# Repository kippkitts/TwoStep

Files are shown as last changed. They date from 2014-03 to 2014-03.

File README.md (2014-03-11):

TwoStep
=======

<a href=http://kippkitts.com/collections/frontpage/products/twostep-stepper-controller-shield>

The TwoStep Controller is a stepper motor controller shield for the Arduino.  It uses two L6470 stepper drivers to drive two motors at 40V, 5A each.  Provided here are the Eagle files for the board.  You can find the TwoStep Controller at the [kippkitts store](http://kippkitts.com/collections/frontpage/products/twostep-stepper-controller-shield).

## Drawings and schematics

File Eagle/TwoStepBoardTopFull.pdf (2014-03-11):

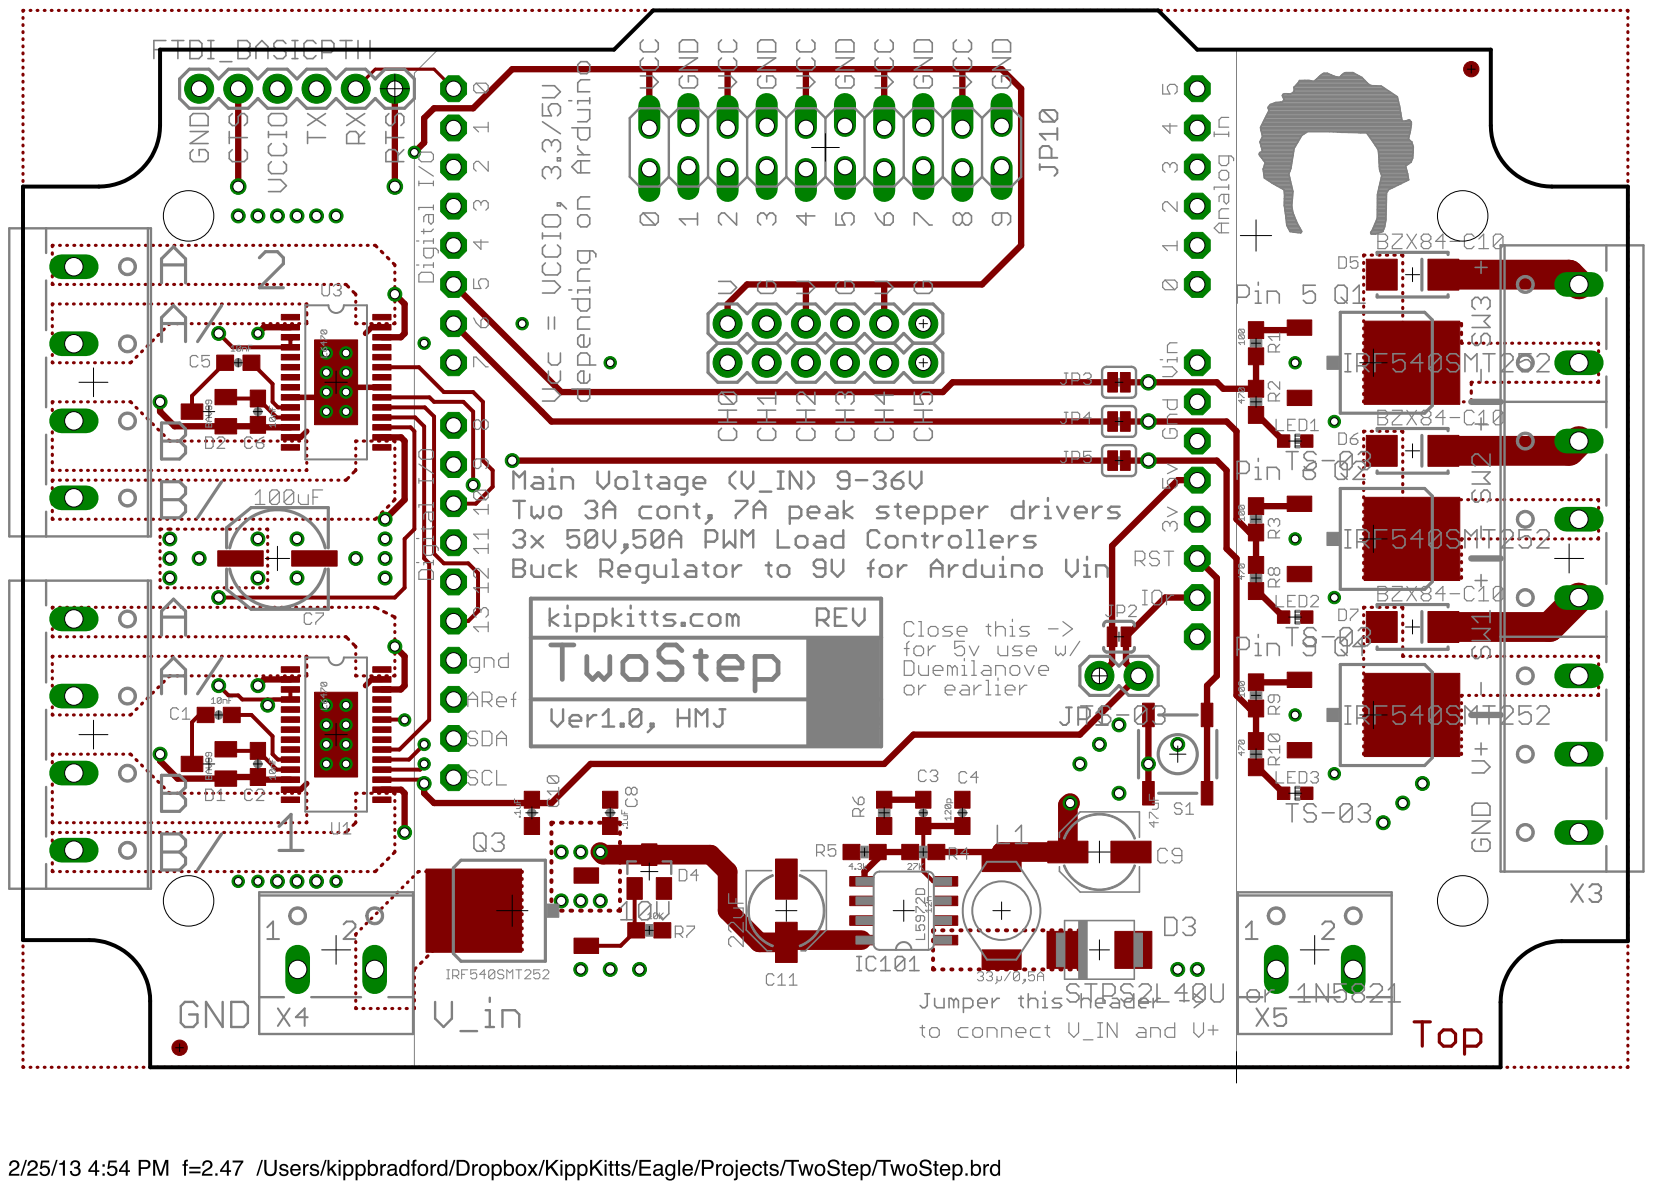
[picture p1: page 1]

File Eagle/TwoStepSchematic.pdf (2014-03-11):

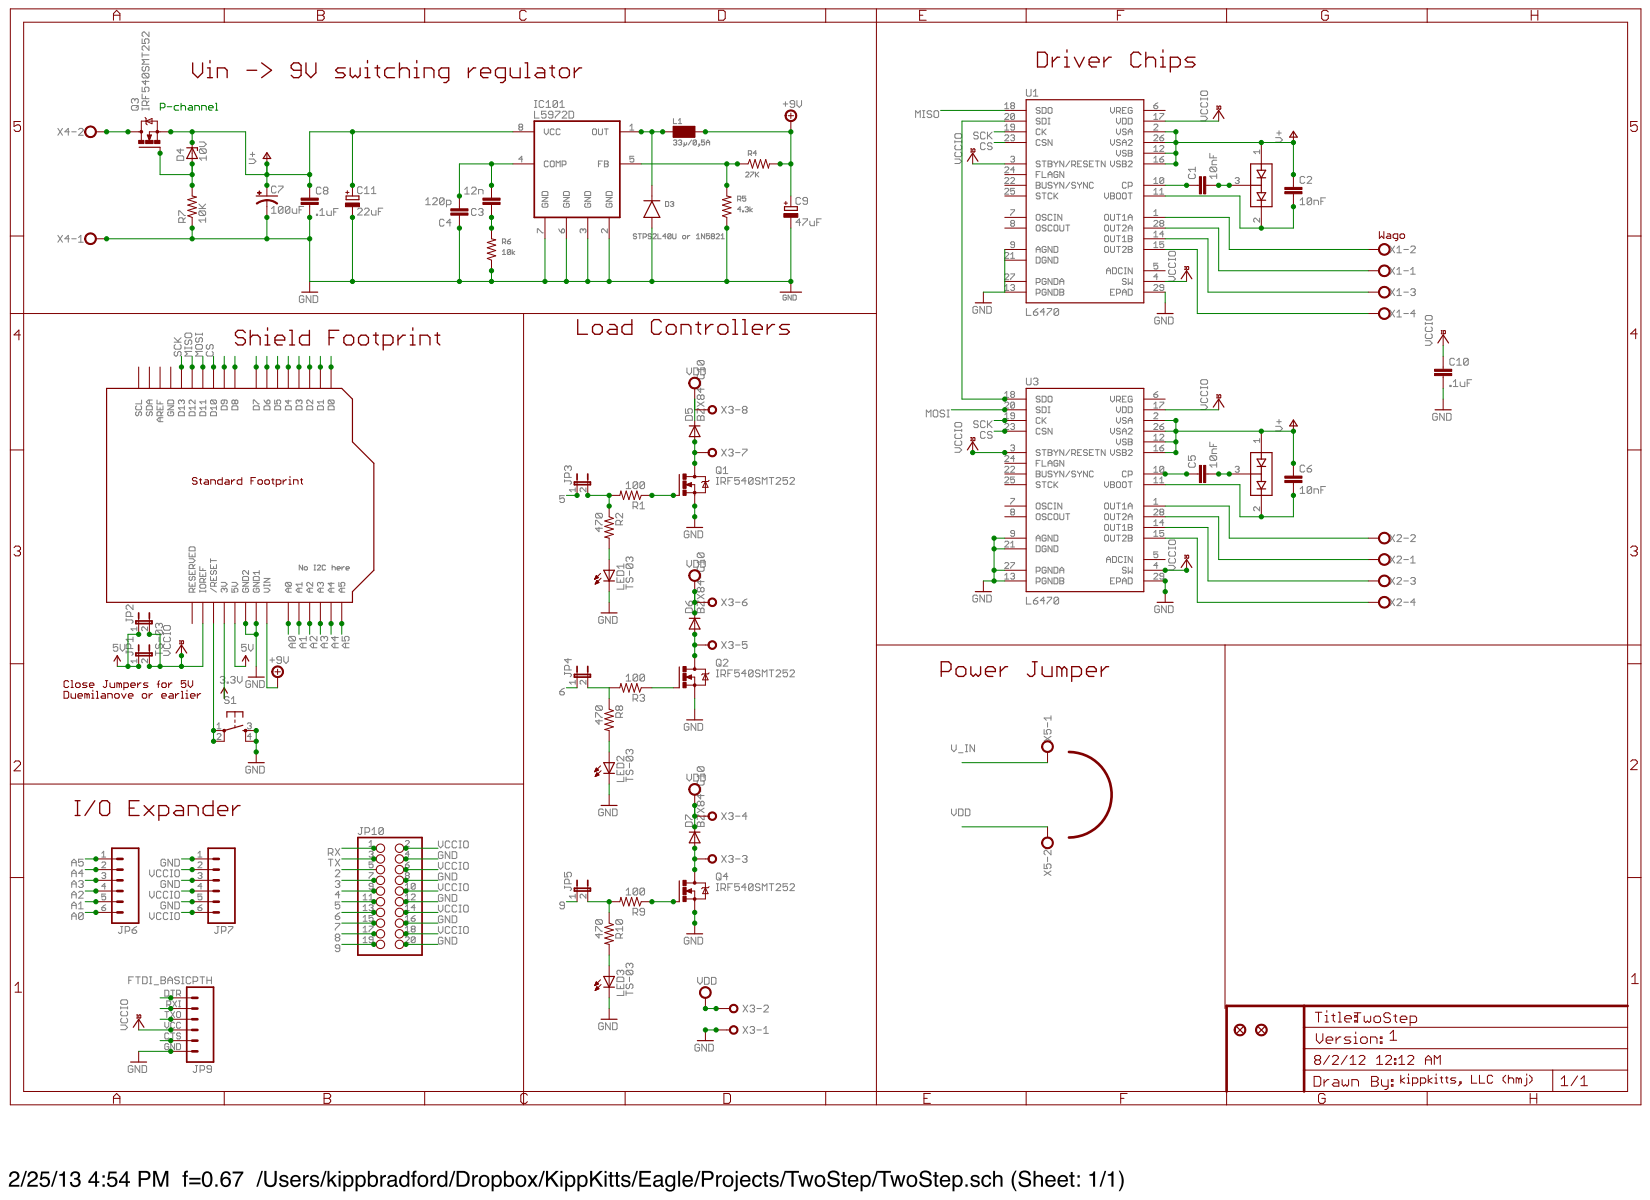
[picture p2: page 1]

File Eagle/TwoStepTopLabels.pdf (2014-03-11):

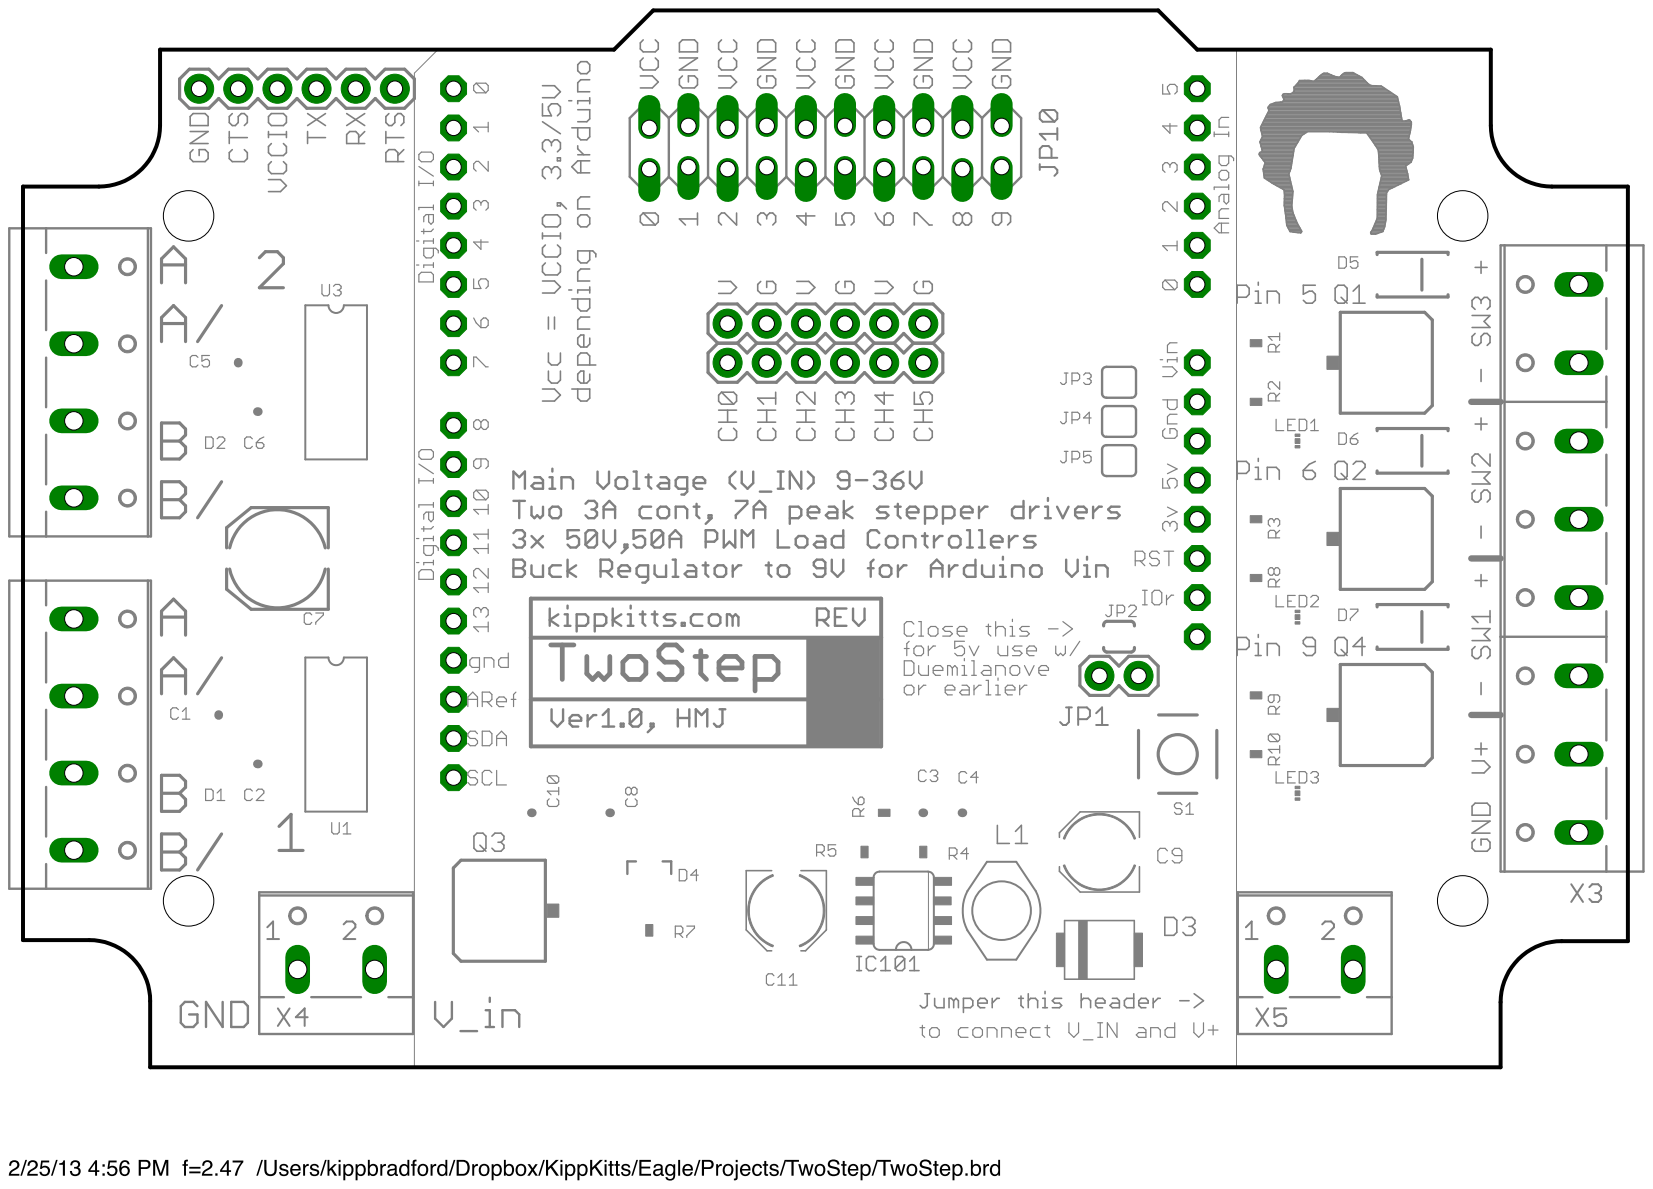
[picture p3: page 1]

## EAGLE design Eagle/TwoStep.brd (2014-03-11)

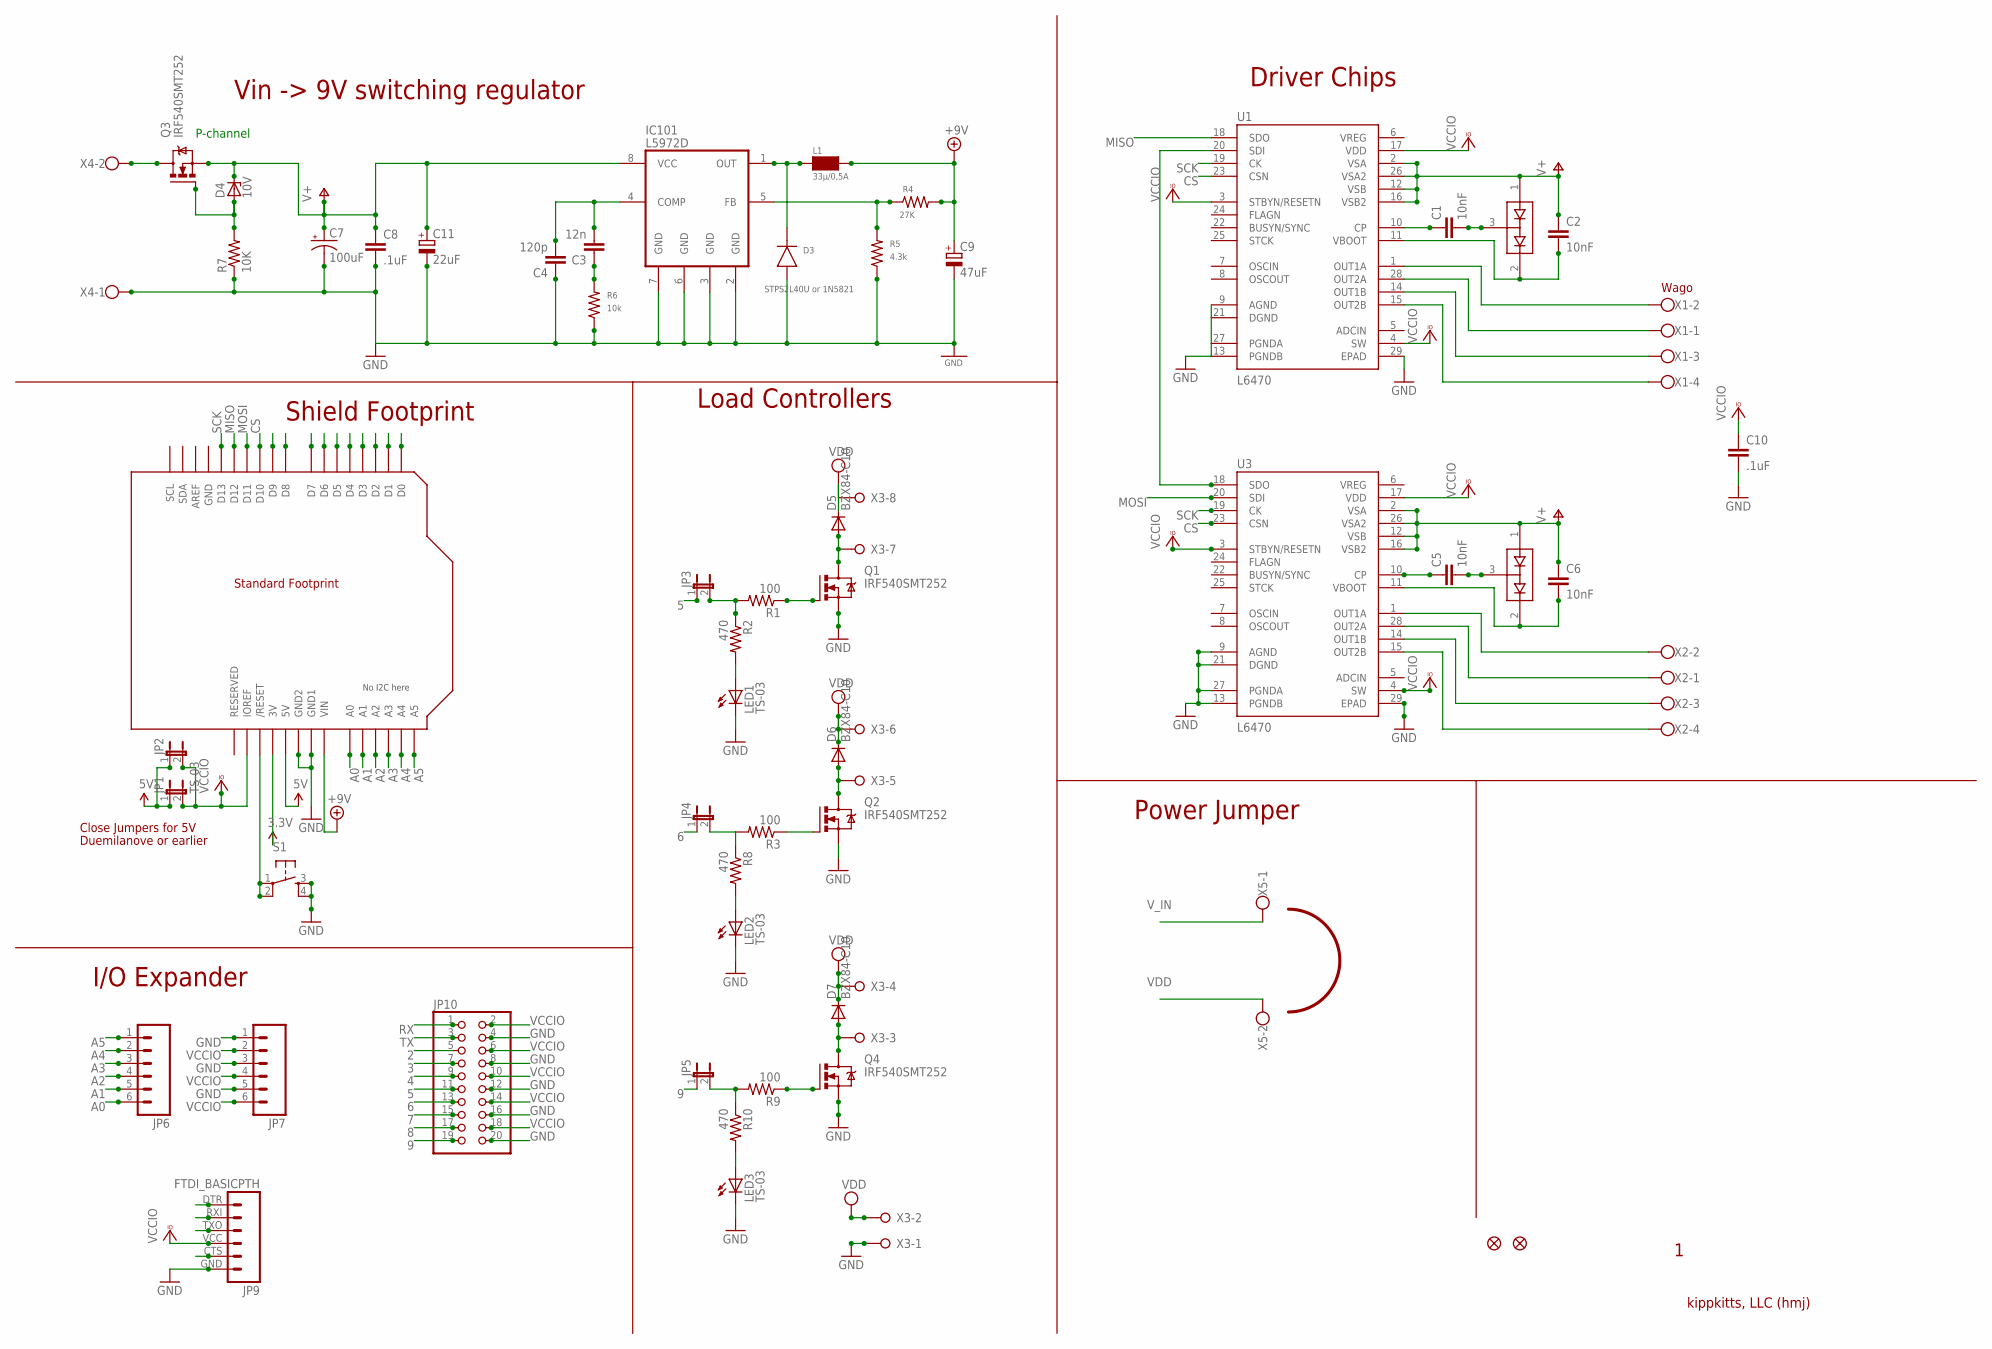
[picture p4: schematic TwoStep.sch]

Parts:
C1, C2, C5, C6: 10nF; 0603-CAP
C3: 12n; 0603-CAP
C4: 120p; 0603-CAP
C7: 100uF; NIPPON_F80
C8, C10: .1uF; 0603-CAP
C9: 47uF; PANASONIC_C
C11: 22uF; PANASONIC_C
D1, D2: BAV99; MISCELLANY_SOT23
D3: STPS2L40U or 1N5821; DO-214AA(SMB)
D4: 10V; SOT23
D5, D6, D7: BZX84-C10; SMA-DIODE_ALT
IC101: L5972D; SO-8
JP1: TS-03; 1X02
JP2: JUMPER-2SMD-NO; SJ_2S-NO
JP3, JP4, JP5: JUMPER-2SMD-NC; SJ_2S
JP6, JP7: M06SIP; 1X06
JP8, JP11: FIDUCIAL1X2; FIDUCIAL-1X2
JP9: FTDI_BASICPTH; FTDI_BASIC
JP10: PINHD-2X10HAND; 2X10HAND
L1: 33µ/0,5A; WE-PD-S
LED1, LED2, LED3: TS-03; CHIP-LED0603
Q1, Q2, Q3, Q4: IRF540SMT252; D-PAK_TO252AA
R1, R3, R9: 100; 0603-RES
R2, R8, R10: 470; 0603-RES
R4: 27K; 0603-RES
R5: 4.3k; 0603-RES
R6: 10k; 0603-RES
R7: 10K; 0603-RES
S1: TAC_SWITCHSMD; TACTILE_SWITCH_SMD
U1, U3: L6470; MISCELLANY_HTSSOP28
U2: ARDUINOR3-BPLACE
X1, X2: W237-4
X3: W237-08P; W237-8P
X4: W237-102
X5: W237-102; MPN 237-102

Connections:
1_OUT1A: U1.1 (OUT1A), X1.2
1_OUT1B: U1.14 (OUT1B), X1.3
1_OUT2A: U1.28 (OUT2A), X1.1
1_OUT2B: U1.15 (OUT2B), X1.4
2: JP10.5, U2.D2
2_OUT1A: U3.1 (OUT1A), X2.2
2_OUT1B: U3.14 (OUT1B), X2.3
2_OUT2A: U3.28 (OUT2A), X2.1
2_OUT2B: U3.15 (OUT2B), X2.4
3: JP10.7, U2.D3
3.3V: U2.3V
4: JP10.9, U2.D4
5: JP3.1, JP10.11, U2.D5
5V: JP1.1, JP2.1, U2.5V
6: JP4.1, JP10.13, U2.D6
7: JP10.15, U2.D7
8: JP10.17, U2.D8
9: JP5.1, JP10.19, U2.D9
+9V: C9.+, L1.2 (4), R4.2, U2.VIN
A0: JP6.6, U2.A0
A1: JP6.5, U2.A1
A2: JP6.4, U2.A2
A3: JP6.3, U2.A3
A4: JP6.2, U2.A4
A5: JP6.1, U2.A5
CS: U1.23 (CSN), U2.D10, U3.23 (CSN)
CTS: JP9.CTS (5)
DTR: JP9.DTR (1)
GND: C4.1, C7.-, C8.2, C9.-, C10.2, C11.-, D3.A, IC101.2 (GND), IC101.3 (GND), IC101.6 (GND), IC101.7 (GND), JP7.1, JP7.3, JP7.5, JP9.GND (6), JP10.4, JP10.8, JP10.12, JP10.16, JP10.20, LED1.C, LED2.C, LED3.C, Q1.3 (S), Q2.3 (S), Q4.3 (S), R5.1, R6.1, R7.1, S1.3, S1.4, U1.9 (AGND), U1.13 (PGNDB), U1.21 (DGND), U1.27 (PGNDA), U1.29 (EPAD), U2.GND, U2.GND1, U2.GND2, U3.9 (AGND), U3.13 (PGNDB), U3.21 (DGND), U3.27 (PGNDA), U3.29 (EPAD), X3.1, X4.1
MISO: U1.18 (SDO), U2.D12
MOSI: U2.D11, U3.20 (SDI)
unnamed: Q1.1 (G), R1.1
unnamed: JP3.2, R1.2, R2.1
unnamed: Q2.1 (G), R3.1
unnamed: LED1.A, R2.2
unnamed: D4.1 (A), Q3.1 (G), R7.2
unnamed: LED2.A, R8.2
unnamed: C1.1, U1.10 (CP)
unnamed: C1.2, D1.3 (COM)
unnamed: C2.2, D1.2 (C2), U1.11 (VBOOT)
unnamed: U1.20 (SDI), U3.18 (SDO)
unnamed: JP4.2, R3.2, R8.1
unnamed: Q4.1 (G), R9.1
unnamed: LED3.A, R10.2
unnamed: C5.1, U3.10 (CP)
unnamed: C5.2, D2.3 (COM)
unnamed: C6.2, D2.2 (C2), U3.11 (VBOOT)
unnamed: JP5.2, R9.2, R10.1
unnamed: D5.A, Q1.4 (D), X3.7
unnamed: S1.1, S1.2, U2.RESET (/RESET)
unnamed: D6.A, Q2.4 (D), X3.5
unnamed: D7.A, Q4.4 (D), X3.3
unnamed: D3.C (K), IC101.1 (OUT), L1.1 (3)
unnamed: IC101.5 (FB), R4.1, R5.2
unnamed: C3.2, C4.2, IC101.4 (COMP)
unnamed: C3.1, R6.2
RX: JP9.RXI (2), JP10.1, U2.D0
SCK: U1.19 (CK), U2.D13, U3.19 (CK)
TX: JP9.TXO (3), JP10.3, U2.D1
V+: C2.1, C6.1, C7.+, C8.1, C11.+, D1.1 (A1), D2.1 (A1), D4.3 (C), IC101.8 (VCC), Q3.3 (S), U1.2 (VSA), U1.12 (VSB), U1.16 (VSB2), U1.26 (VSA2), U3.2 (VSA), U3.12 (VSB), U3.16 (VSB2), U3.26 (VSA2)
VCCIO: C10.1, JP1.2, JP2.2, JP7.2, JP7.4, JP7.6, JP9.VCC (4), JP10.2, JP10.6, JP10.10, JP10.14, JP10.18, U1.3 (STBYN/RESETN), U1.4 (SW), U1.17 (VDD), U2.IOREF, U3.3 (STBYN/RESETN), U3.4 (SW), U3.17 (VDD)
VDD: D5.C, D6.C, D7.C, X3.2, X3.4, X3.6, X3.8, X5.2
V_IN: Q3.4 (D), X4.2, X5.1

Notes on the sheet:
Wago
kippkitts, LLC (hmj)
Driver Chips
Vin -> 9V switching regulator
Shield Footprint
Close Jumpers for 5V
Duemilanove or earlier
P-channel
Load Controllers
I/O Expander
Power Jumper

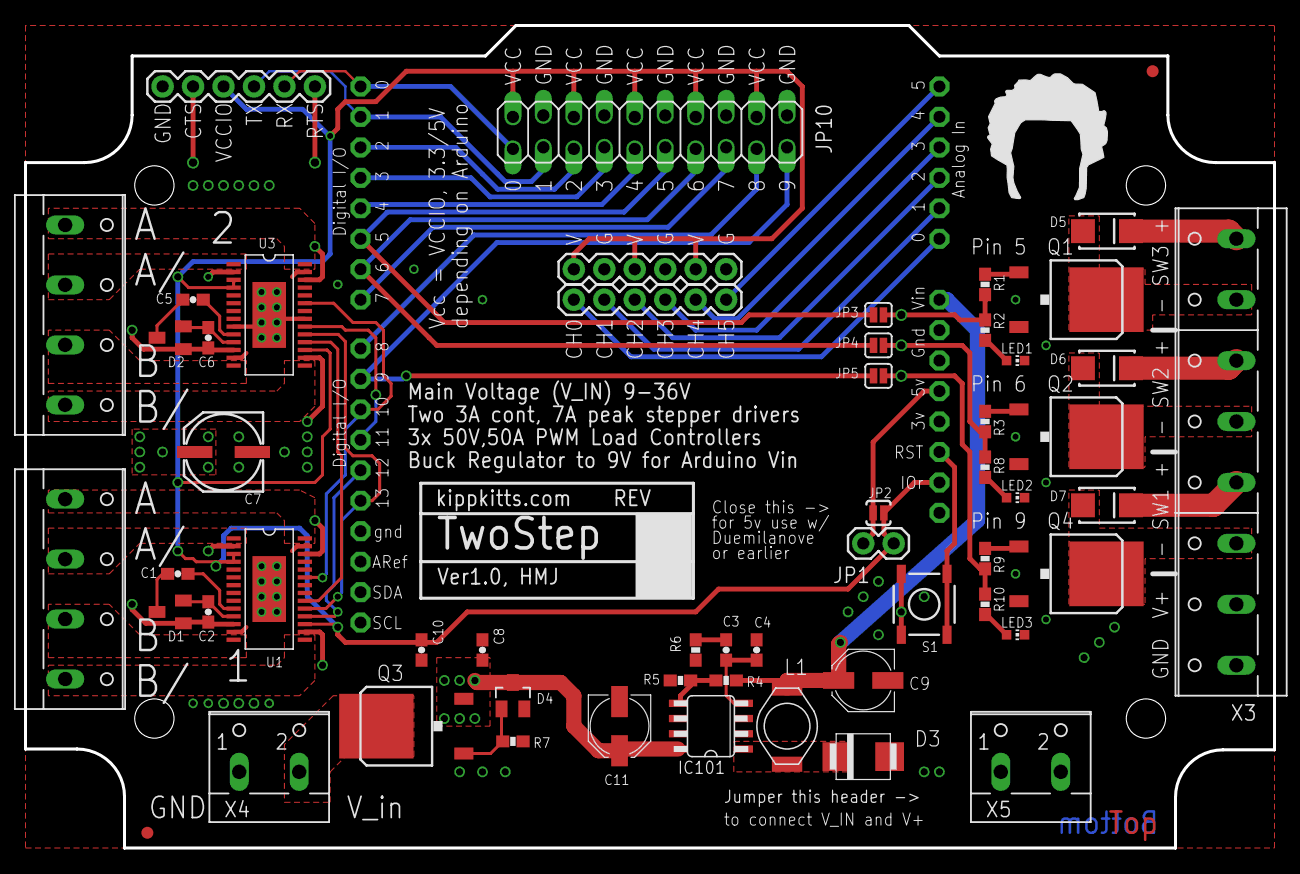
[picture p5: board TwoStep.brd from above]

Board: 2 copper layers, 104.1 x 68.6 mm, 58 parts (0 on the bottom side), 60 nets.

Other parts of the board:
KK_LOGO: TOP_DOCU_10MM

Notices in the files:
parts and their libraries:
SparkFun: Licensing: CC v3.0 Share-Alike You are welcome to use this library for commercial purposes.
